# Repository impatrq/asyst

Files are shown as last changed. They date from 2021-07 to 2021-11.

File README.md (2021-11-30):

<!-- PROJECT LOGO -->
<br />
<p align="center">
  <a href="https://github.com/impatrq/asyst">
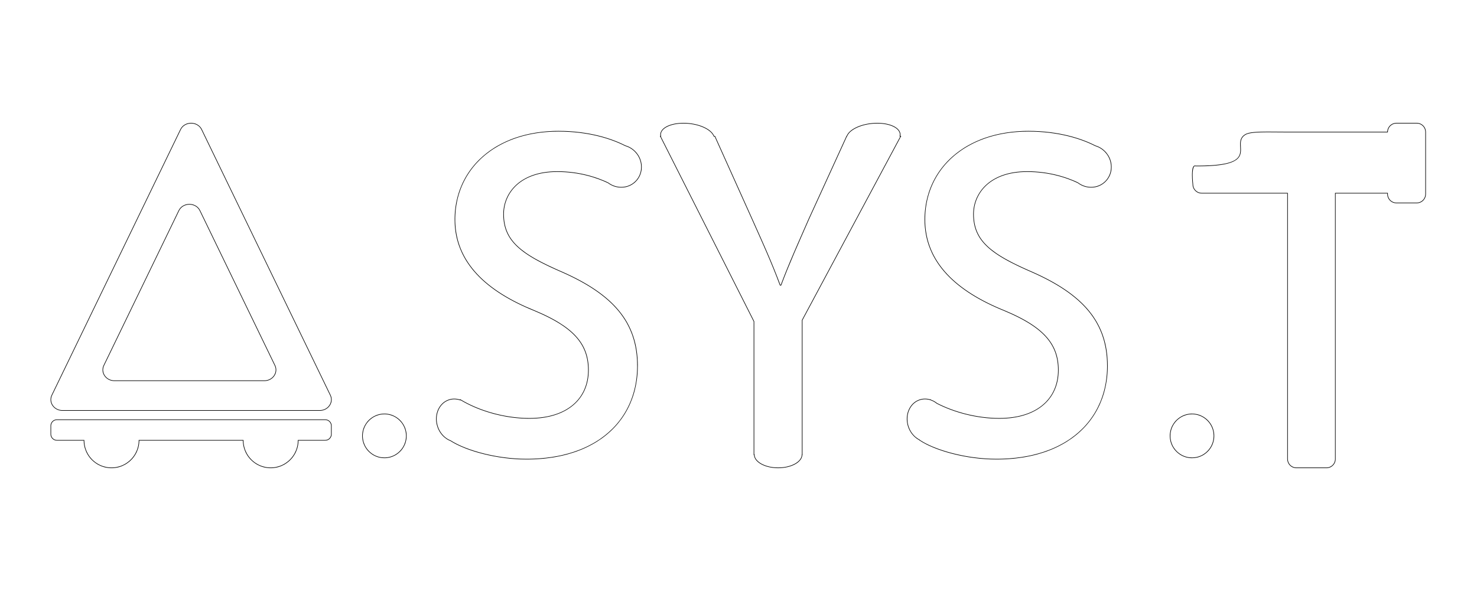
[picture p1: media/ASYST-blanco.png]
    
  </a>

  <h3 align="center">A.SYS.T</h3>
  <h4 align="center">Aeronautical system of tools</h4>

  <p align="center">
    Pedidos inteligentes
    <!-- TABLE OF CONTENTS -->
<details open="open">
  <summary>Contenidos</summary>
  <ol>
    <li>
      <a href="#sobre-el-proyecto">Sobre el Proyecto</a>
    </li>
    <!-- <li>
      <a href="#getting-started">Getting Started</a>
      <ul>
        <li><a href="#prerequisites">Prerequisites</a></li>
        <li><a href="#installation">Installation</a></li>
      </ul>
    </li> -->
    <li><a href="#manual-de-uso">Manual de Uso</a></li>
    <li><a href="#licencia">Licencia</a></li>
    <li><a href="#contacto">Contacto</a></li>
    <!-- <li><a href="#agradecimientos">Agradecimientos</a></li> -->
  </ol>
</details>
<!-- ABOUT THE PROJECT -->

## Sobre el Proyecto

**A.SYS.T (*Aeronautical system of tools*)** es un sistema que facilita el proceso de pedido y entrega de herramientas e insumos en un circuito aeronautico.
**A.SYS.T** ofrece una aplicación con una interfaz amigable en la que los trabajadores ingresarán para hacer los pedidos de herramientas e insumos que necesitarán para efectuar su trabajo, esta app cse comunicará con un servidor que generará un registro digital el cual responderá `¿Quién?, ¿Qué? y ¿Cuándo?` y, a su vez, enviará el pedido para que sea confirmado y posteriormente armado. Una vez listo el pedido un carrito autonomo recibirá el comando para iniciar su viaje y lo transportará hacia el sector de trabajo designado donde los trabajadores podrán retirarlo, usarlo y, posteriormente, devolverlo.

**Benecificios:**
* Al llevar un registro digital de los pedidos se elimina cualquier volumen de papel que se utilizaría para este mismo fin
* Como se puede fitrar el registro ante varios parámetros, se agiliza considerablemente la búsqueda de estos
* Como los pedidos se pueden hacer de forma remota, se reduce el tiempo que lleva realizar el pedido
* Se puede ahorrar el registro de devolución, pues una vez finalizado su uso el carro vuelve y marca como realizada su devolución
* El trabajador hará un menor esfuerzo físico y utilizará menos de su tiempo en el transporte de lo pedido

### Frameworks

* [Django](https://www.djangoproject.com/)
* [Bulma](https://bulma.io/)
* [uPython](https://micropython.org/)

<!-- GETTING STARTED -->
<!-- ## Getting Started

This is an example of how you may give instructions on setting up your project locally.
To get a local copy up and running follow these simple example steps.

### Prerequisites

This is an example of how to list things you need to use the software and how to install them.
* npm
  ```sh
  npm install npm@latest -g
  ```

### Installation

1. Get a free API Key at [https://example.com](https://example.com)
2. Clone the repo
   ```sh
   git clone https://github.com/your_username_/Project-Name.git
   ```
3. Install NPM packages
   ```sh
   npm install
   ```
4. Enter your API in `config.js`
   ```JS
   const API_KEY = 'ENTER YOUR API';
   ``` -->

<!-- USAGE EXAMPLES -->
## Manual de Uso

Manual de uso para el sistema que ofrece A.SYS.T
**[Documentation](https://github.com/impatrq/asyst/tree/master/Manual-de-usuario)**

<!-- LICENSE -->
## Licencia

Distribuido bajo la licencia MIT. Consulte `LICENSE` para obtener más información.

<!-- Distribuido bajo la licencia MIT. Consulte `LICENSE` para obtener más información.

<!-- CONTACTO -->
## Contacto

E-Mail equipo *A.SYS.T* - asyst.official@gmail.com -
Instagram equipo *A.SYS.T* - [a.sys.t](https://www.instagram.com/a.sys.t/)

Link del Proyecto: [github.com/impatrq/ayst](https://github.com/impatrq/asyst)

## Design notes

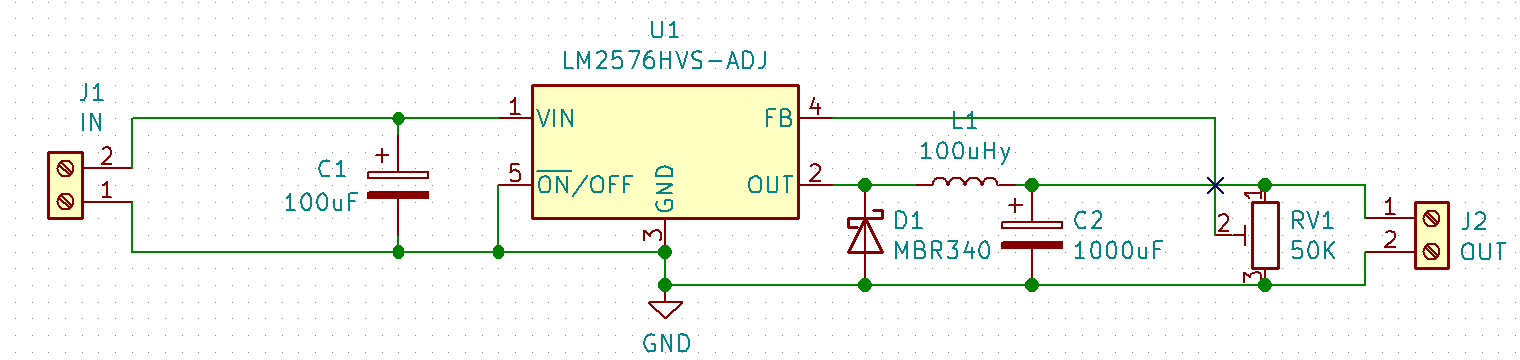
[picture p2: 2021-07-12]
Documentacion/Alimentacion-Digital/Esquemático.png

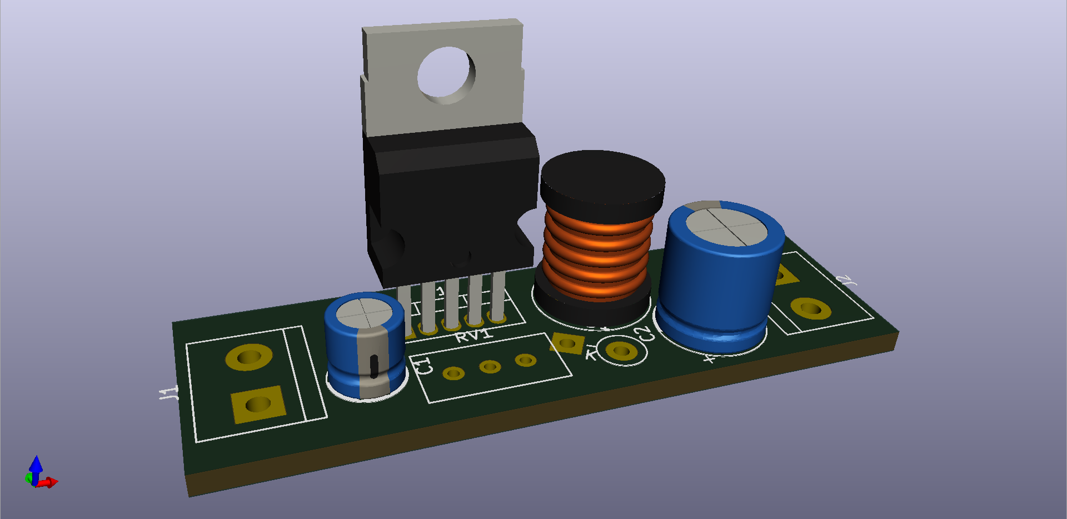
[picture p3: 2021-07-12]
Documentacion/Alimentacion-Digital/circuito 3D.png

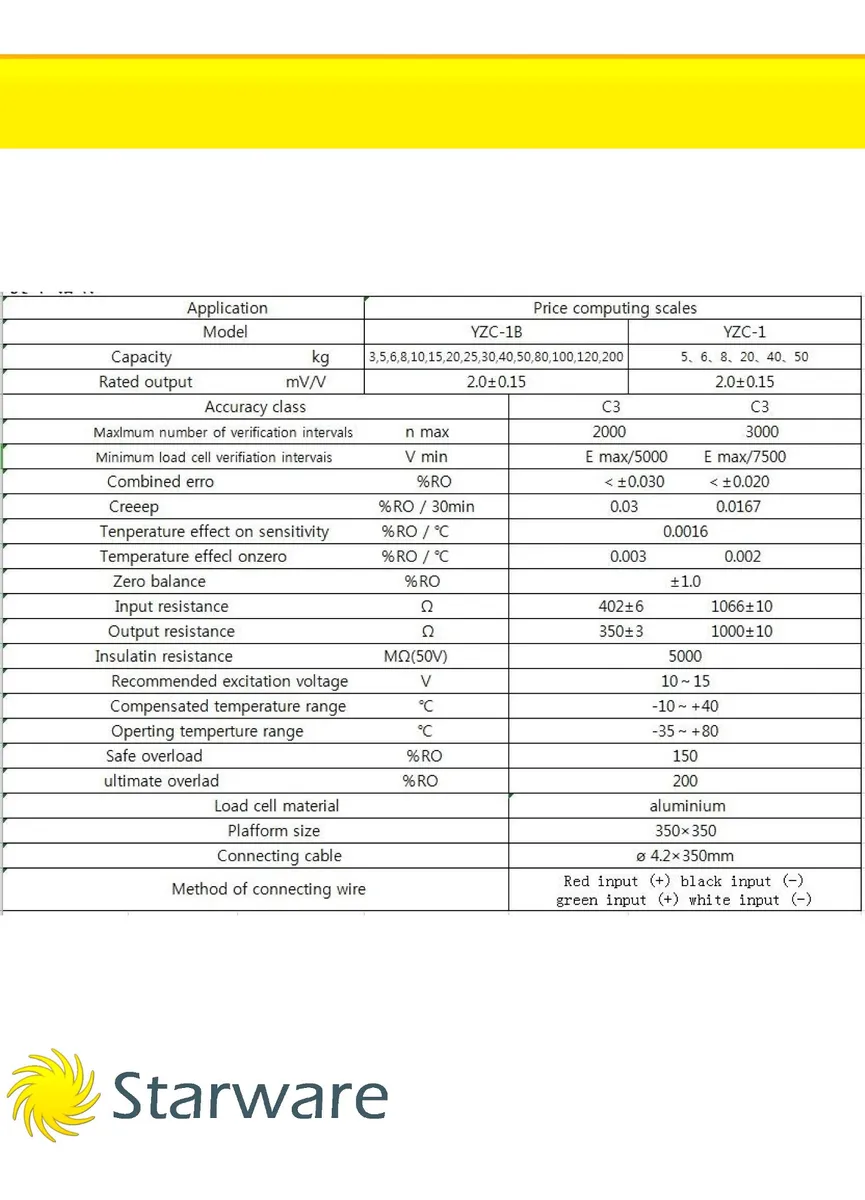
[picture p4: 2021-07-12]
Documentacion/Celda-de-carga/Hoja de datos.png

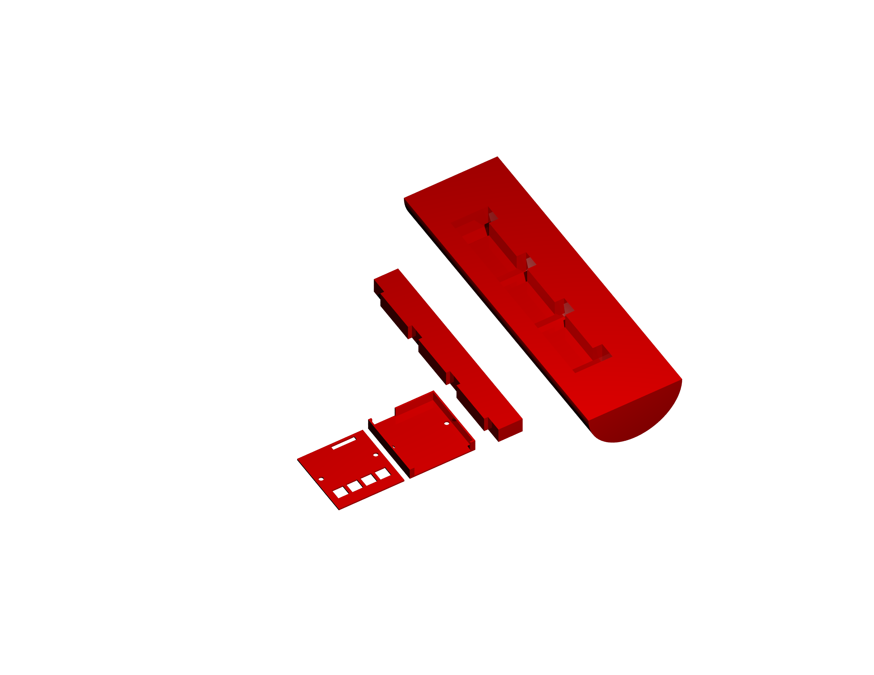
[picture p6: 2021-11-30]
Modelados-3D/soporte-ifr+magnetico/Impresion3D.png

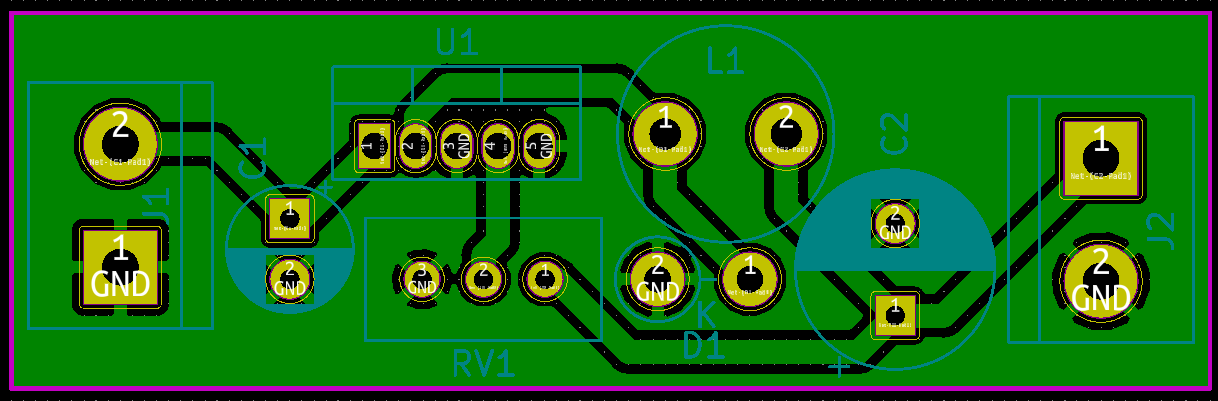
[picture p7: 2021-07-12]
Documentacion/Alimentacion-Digital/PCB.png

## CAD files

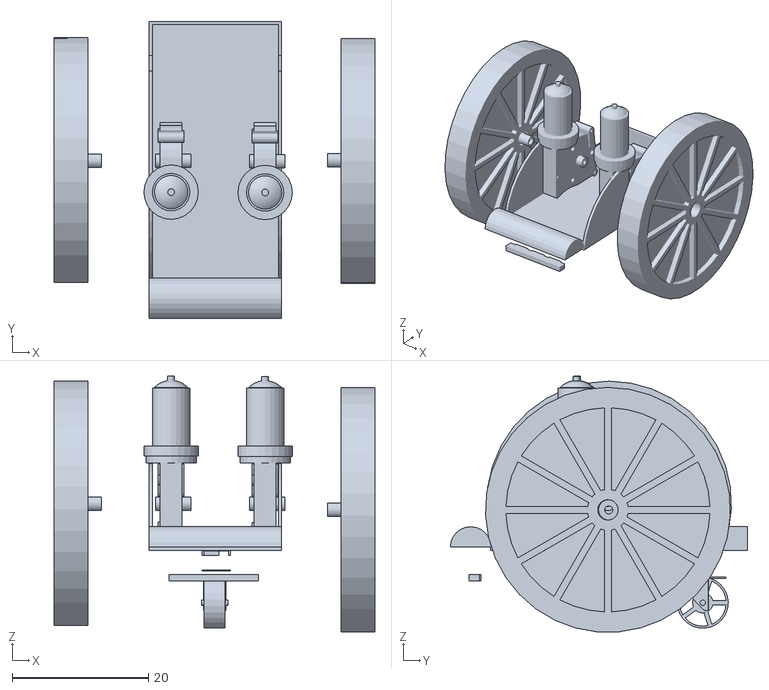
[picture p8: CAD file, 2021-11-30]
Modelados-3D/Carrito-completo/objetos.stl
47.2 x 43.7 x 37.6

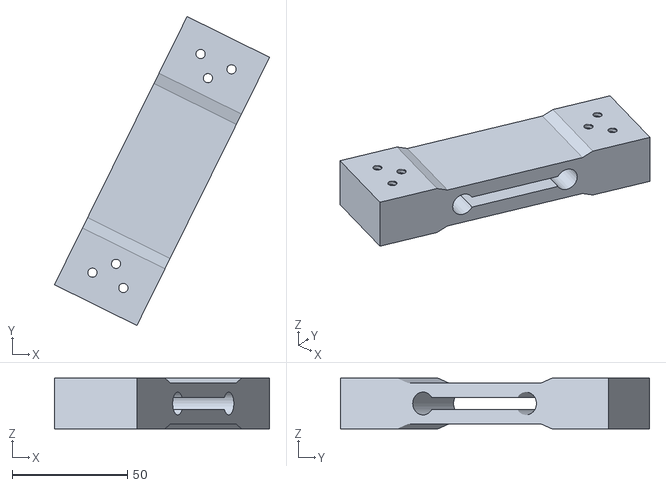
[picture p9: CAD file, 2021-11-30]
Modelados-3D/celda-de-carga/Celda.stl
93.5 x 134.3 x 22.0

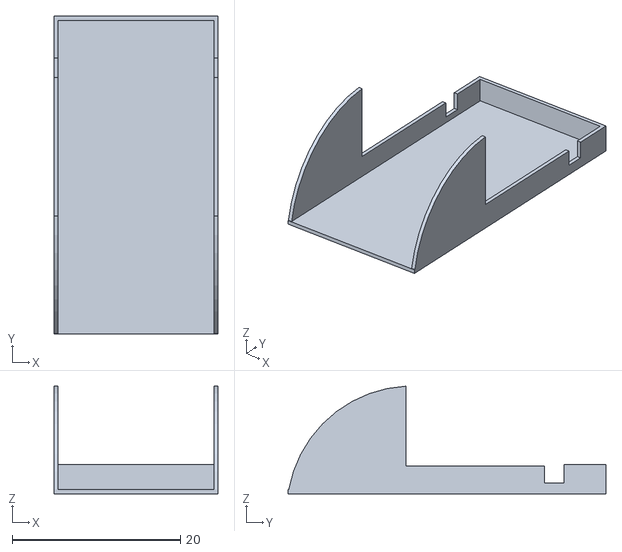
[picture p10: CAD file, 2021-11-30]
Modelados-3D/estructura/estructura3d.stl
19.5 x 37.8 x 12.8

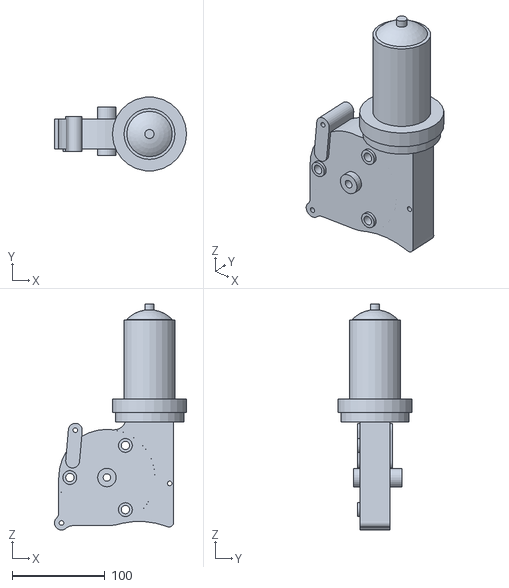
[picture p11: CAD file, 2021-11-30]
Modelados-3D/motor/motor.stl
142.6 x 79.4 x 244.0

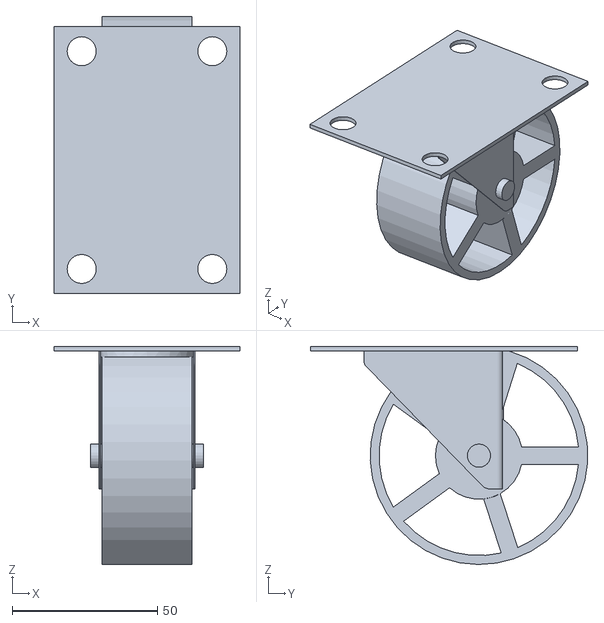
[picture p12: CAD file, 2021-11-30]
Modelados-3D/rueda-giratoria/rueda giratoria3D.stl
64.0 x 95.5 x 75.1

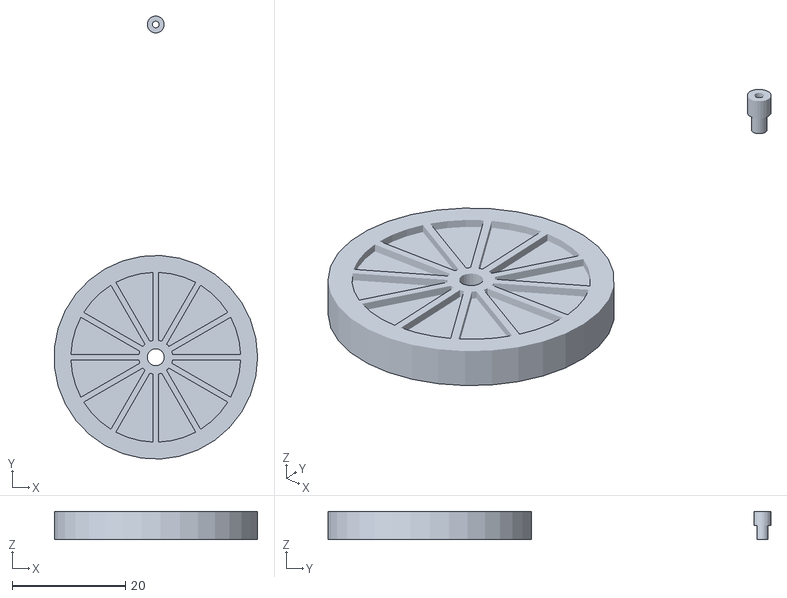
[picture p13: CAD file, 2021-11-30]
Modelados-3D/rueda/rueda+adaptador eje motor3d.stl
35.9 x 78.3 x 5.00

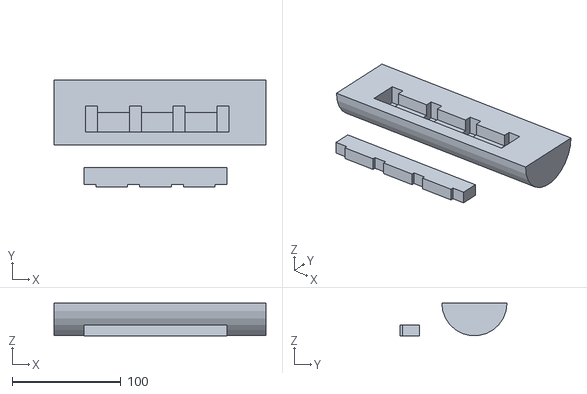
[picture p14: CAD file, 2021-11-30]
Modelados-3D/soporte-ifr+magnetico/soporte sensores.stl
195.0 x 98.4 x 30.0

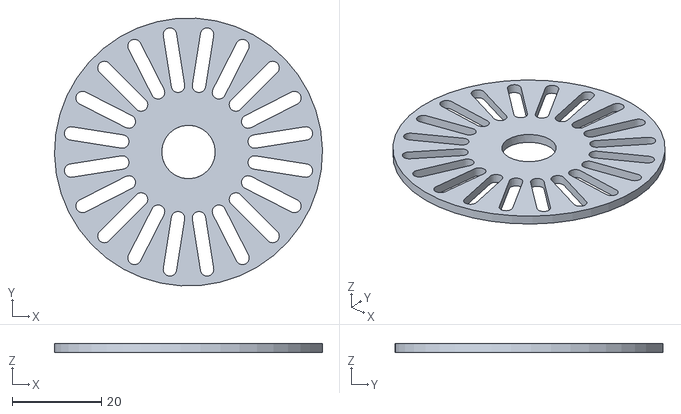
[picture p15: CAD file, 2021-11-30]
Modelados-3D/rueda-optica-rpm/encoder opt.stl
60.0 x 59.9 x 2.00

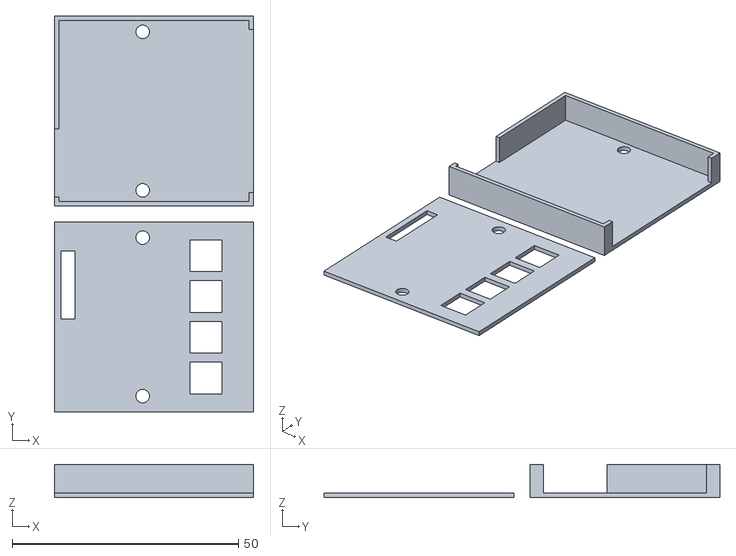
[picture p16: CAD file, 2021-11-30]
Modelados-3D/soporte-ifr+magnetico/calibrador.stl
44.0 x 87.4 x 7.37

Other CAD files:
Documentacion/Celda-de-carga/Celda.dwg
Modelados-3D/rueda-optica-rpm/rueda optica rpm.dwg
Modelados-3D/estructura/estructura.dwg
Modelados-3D/rueda-giratoria/rueda giratoria.dwg
Modelados-3D/rueda/ruedaa+daptador eje motor.dwg
Modelados-3D/soporte-ifr+magnetico/Dibujo1.dwg
Modelados-3D/Carrito-completo/objetos.dwg
Modelados-3D/celda-de-carga/Celda.dwg
Modelados-3D/estructura/estructura3d.dwg
Modelados-3D/motor/motor.dwg
Modelados-3D/rueda-giratoria/rueda giratoria3D.dwg
Modelados-3D/rueda/rueda+adaptador eje motor3d.dwg

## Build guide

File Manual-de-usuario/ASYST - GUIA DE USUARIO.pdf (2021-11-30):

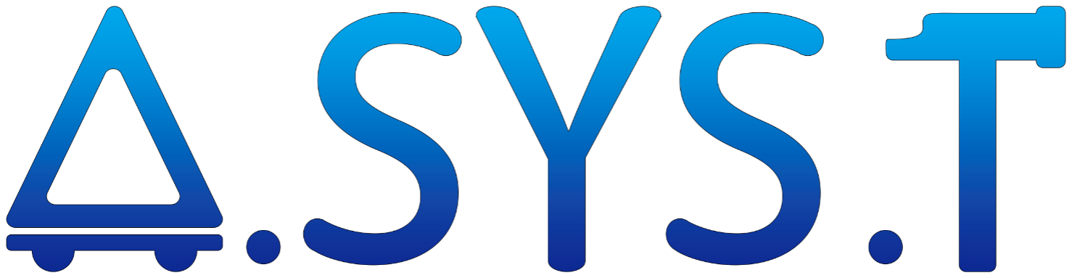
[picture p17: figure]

E.E.S.T. N°7 “T.R.Q.”
Juan B. Justo 79, Quilmes
asyst.official@gmail.com
Proyecto A.SYS.T; 2021

# “AERONAUTIC SYSTEM OF TOOLS”

# MANUAL DE USUARIO

INTRODUCCIÓN | 2
Por qué elegir A.SYS.T: | 2
A. APLICACIÓN | 3
1.0. Identifíquese: | 3
2.0. Interfaz de usuario: | 4
2.1. Interfaz de Trabajador: | 5
2.2. Interfaz de Staff: | 6
B. VEHÍCULOS | 9
2.0. Recorrido por el vehículo: | 10
2.1. Envío del vehículo: | 10
2.2. Viaje | 11
2.3. Destino: | 11
2.4. Regreso: | 11
2.5 Devolución: | 11
C. INSTALACIÓN | 12

## INTRODUCCIÓN

## Por qué elegir A.SYS.T:

Comparativamente entre lo que nuestro sistema digital de registro de pedidos plantea y lo que el anticuado sistema ofrece vemos mejoras en:

✔Considerable reducción del espacio físico ocupado por los archivos en papel.
✔Gran agilización a la hora de la búsqueda entre los registros. ✔Reducción del tiempo necesario para hacer los pedidos.
✔Reducción de riesgos de daño o extravío de la documentación.

Por otra parte, cuando comparamos nuestra alternativa del transporte de los carros de herramientas con el viaje manual observamos las siguientes mejoras:

✔Se puede ahorrar el registro de devolución, pues una vez finalizado su uso el carro vuelve y marca como realizada la devolución.
✔El trabajador hará un menor esfuerzo físico e invertirá menos tiempo en el transporte de herramientas.

Teniendo en cuenta el análisis de costo/beneficio, podemos concluir que:

✔Este producto ofrece una mejora a un sistema que ya existe, volviéndolo más ágil y seguro, dos factores que en un taller aeronáutico consideramos esenciales.
✔Ofrece mucha mayor seguridad en el archivado, ya que no depende de documentos físicos que puedan dañarse o perderse.
✔Se reduce la cantidad de esfuerzo físico realizado por los trabajadores, mientras que se asegura la fluidez y comodidad de la rutina laboral, resultando en horas de trabajo más productivas y menos interrumpidas.
✔El uso de su interfaz no requiere más que una computadora o un teléfono móvil, volviéndo accesible en prácticamente cualquier taller, ya que no se necesitará realizar compras adicionales.

## A. APLICACIÓN

## 1.0. Identifíquese:

Cada trabajador puede y deberá crear un perfil mediante el cual puede utilizar todas las funciones de nuestro sistema. Dependiendo de la clase de usuario tendrá acceso a un panel u otro.

- El primer tipo de usuario que abarca el sistema es el “Trabajador”. Este usuario es el que tiene el rol en el taller de pedir y utilizar las herramientas.
- El segundo tipo de usuario es el “Staff”. Este usuario corresponde a los encargados de la oficina técnica y el pañol. Sus
funciones son las de gestionar los pedidos
realizados por los “Trabajadores”, y

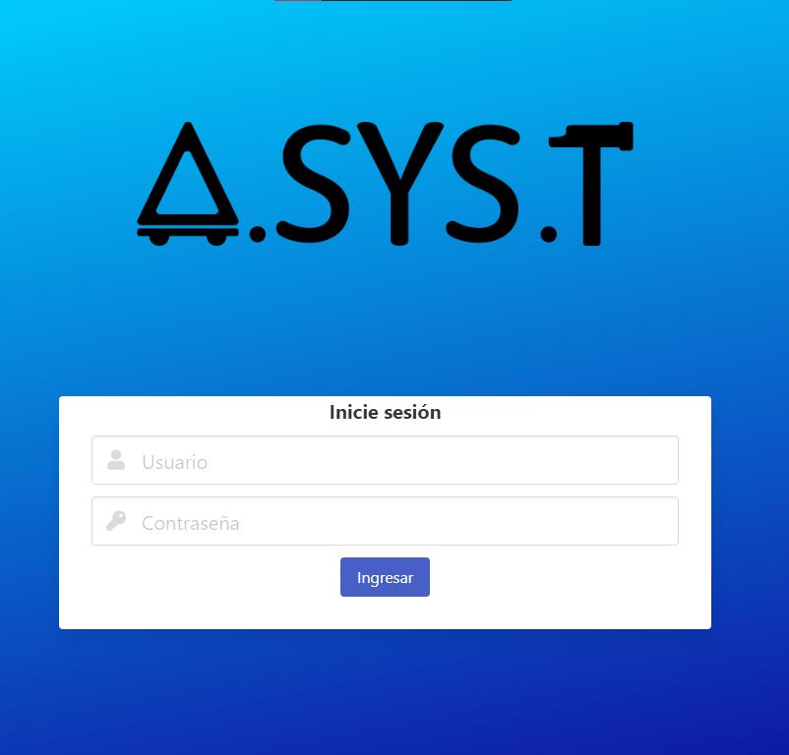
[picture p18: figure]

cargar los vehículos con las herramientas e insumos que el primero solicita; también debe gestionar el Stock del taller, tener acceso a los registros de pedidos previos y gestionar la flota de vehículos autónomos.

Cuando ingrese por primera vez al sistema, verá una pantalla rotulada “inicie sesión”. Si tiene ya tiene una cuenta puede ingresar y seguir la guía en la página 4.
Si no posee una cuenta deberá dirigirse a la pantalla de registro, donde se le pedirá que ingrese 5 datos, los cuales son:
- Su nombre de usuario con el cual se
identificará en el sistema.
- Su nombre completo, para que sus superiores puedan identificarlo en el sistema.
- Su correo electrónico laboral, al cual le llegará un correo en caso de que solicite restablecer su cuenta.
- Su contraseña, será pedida dos veces para corroborar que la ha escrito correctamente.
- El rol que posee en la empresa, marque la opción “Es staff” en caso de que sea un trabajador del pañol o la oficina técnica. Caso contrario no
debería seleccionar esta opción ya
que no le servirá para el trabajo.

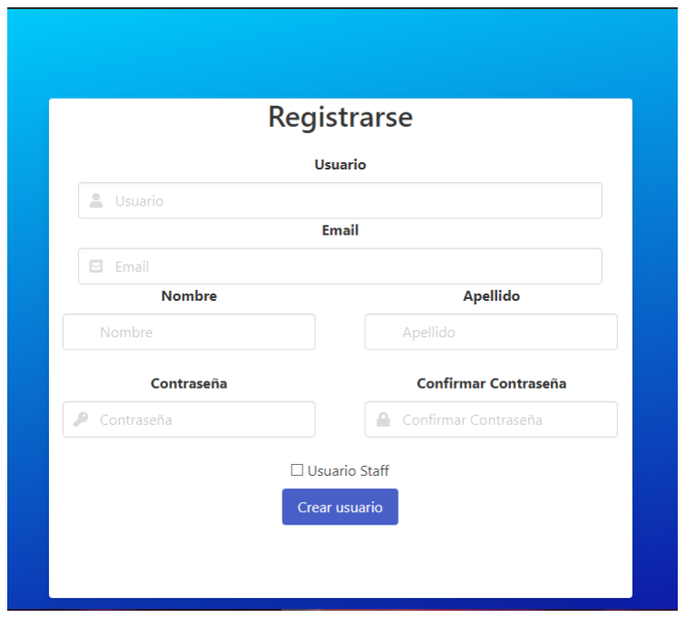
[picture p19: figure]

Con estos datos podrá crear su cuenta y comenzar a utilizarla. En caso de que tenga algún dato faltante o erróneo (véase un nombre de usuario ya existente o la contraseña mal confirmada), el proceso será interrumpido y se le informará para que reintente la creación de su cuenta.

## 2.0. Interfaz de usuario:

La interfaz es bastante intuitiva de por sí, ya que pensamos en la experiencia de usuario como principal factor, sin embargo no está de más tener un par de consideraciones en cuenta.

En todas las interfaces (excepto la de iniciar sesión y registrarse), tendrá una barra superior por la que podrá navegar entre las distintas funciones que el sistema tiene para ofrecer, esta se encuentra en la esquina superior derecha de la pantalla, y se divide en dos grupos.

1) El primer grupo se trata de las funciones del sistema, probablemente las opciones que tenga disponibles no sean las mismas que se ilustran, pero la función es la misma: alternar entre las funciones del sistema con un click.
2) El segundo apartado es ese icono que se ve a la derecha, si posa el mouse sobre este icono podrá ver la inscripción “logout”. Es decir que con este botón cerrará la sesión y volverá a la pantalla de Inicio de Sesión.
Una vez con eso aclarado podemos continuar con la interfaz específica de cada tipo de usuario.

### 2.1. Interfaz de Trabajador:

Lo primero que se encuentra un usuario de este estilo al ingresar es una pantalla donde puede ver el Stock del taller y seleccionar las cosas que requiere y en que cantidad lo requiere. Nótese que realmente la lista es bastante larga. Se puede observar que en el encabezado de la lista de búsqueda hay tanto un filtro de escritura (barra superior) como también hay un filtro de opciones múltiples: “Todos/Herramientas/Insumos”.

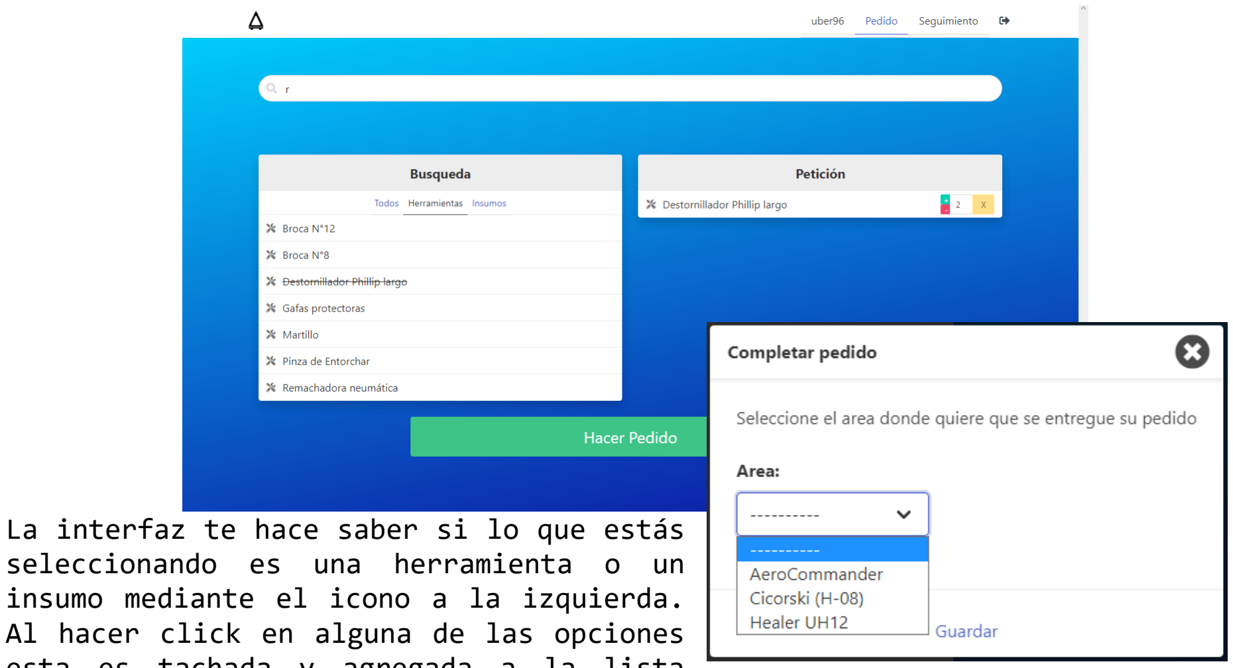
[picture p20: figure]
seleccionando es una herramienta o un

La interfaz te hace saber si lo que estás

insumo mediante el icono a la izquierda.
Al hacer click en alguna de las opciones
esta es tachada y agregada a la lista
derecha. Se puede ver que a la izquierda de cada elemento de la lista de seleccionados hay un número y tres botones. El numero es la cantidad de ese insumo que se solicita, el cual se modifica mediante los botones “+/-”, si se equivocó o cambió de parecer el boton amarillo “X” revierte la selección y lo destacha de la lista izquierda.

Cuando se terminó de pedir lo que requiere, se clickea el botón verde “hacer pedido”, momento en el cual se despliega una ventana emergente, la cual le permite seleccionar el área al que debería llegar el pedido.

Una vez completado el pedido se envía a la oficina técnica o en su defecto al pañol. El trabajador se redirecciona a la segunda pantalla, denominada “Seguimiento”. Desde esta zona de la interfaz puede seguir su orden en tiempo real, teniendo información de si fué aprobado o no su pedido y donde se encuentra este.

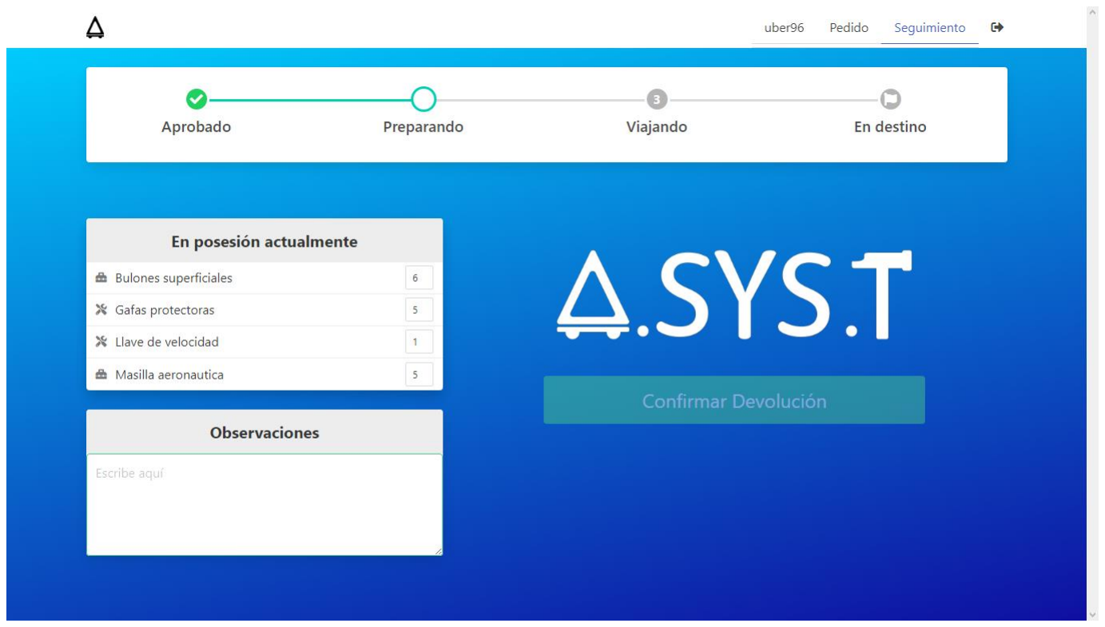
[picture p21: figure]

Como se ve en la imagen adjunta, el botón de la devolución está deshabilitado. Esto es porque no se puede hacer una devolución mientras no se tengan en posesión las herramientas. A la derecha hay dos cuadros, uno es donde se hace una observación al momento de devolver las herramientas, de forma tal que quede registrado si por ejemplo se dañó una herramienta o se devuelven insumos que se habían solicitado de más, el otro es un recordatorio de las herramientas que se tienen a cargo.

Este es el abanico de opciones y funcionalidades que tienen los Trabajadores.

### 2.2. Interfaz de Staff:

La interfaz de los usuarios de clase “Staff” es bastante más extensa, ya que son los que mantienen y le dan vida al sistema, además de ser el nexo entre la flota de vehículos autónomos y los trabajadores.

Al iniciar sesión en una cuenta “Staff” lo primero que vemos es la pantalla a la que denominamos “pedidos”. Esta pantalla es bastante intuitiva, se ven múltiples tarjetas, cada una con
fecha, nombre y la lista de herramientas
que fué solicitada.

Las tarjetas tienen algunas herramientas que se muestran, pero si la lista es lo suficientemente larga se ve un “ver mas” el cual despliega una ventana emergente al ser clickeada, en la cual se detallan
todos | los | insumos | que | solicitó | el
usuario.

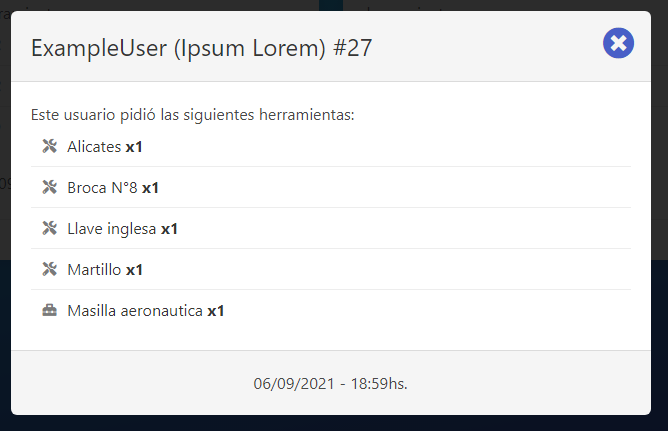
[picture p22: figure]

En el pie de cada tarjeta se ven dos botones, se entiende que uno es para aprobar y otro es para rechazar el pedido en cuestión. Al ser seleccionada la opción de aprobación el sistema leerá los vehículos disponibles y asignará uno si está disponible, diciéndole a usted en qué vehículo deberá cargar las herramientas. De otra manera no aceptará el pedido y le informará a usted que la flota está en uso para que reintente más adelante. Caso contrario se despliega una ventana diferente, en el cual se deberá escribir el motivo del rechazo. Este mensaje será visto por el Trabajador y quedará grabado en los registros.

Otra función que tiene su perfil Staff es el del Stock. El funcionamiento de esta es bastante similar a su contraparte del lado “trabajador”, ya que
posee | dos | filtros: | uno | por | nombre | y | otro | por | opción | múltiple
“Todos/Herramientas/Insumos”, la lista se encuentra ordenada de forma alfabética, y tiene dos botones en cada elemento de la lista que son “editar y eliminar”. Al presionar eliminar se remueve de la base de datos esta herramienta, como indica su nombre.

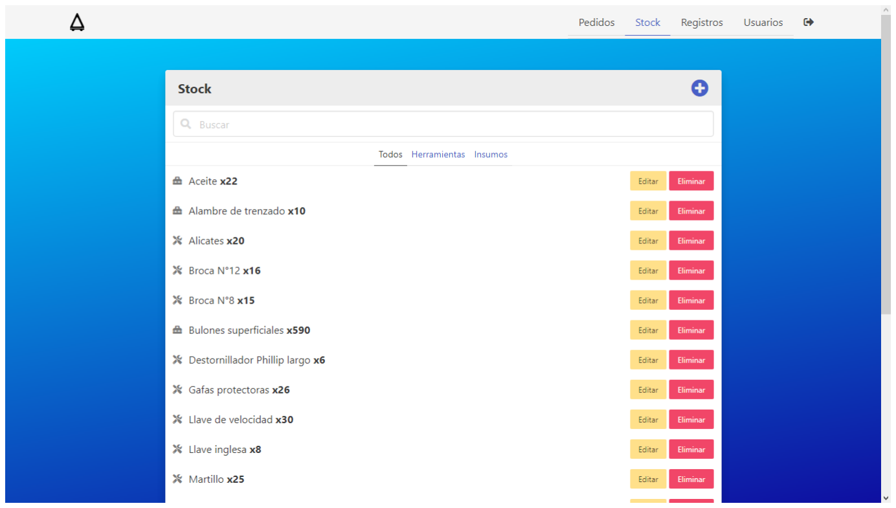
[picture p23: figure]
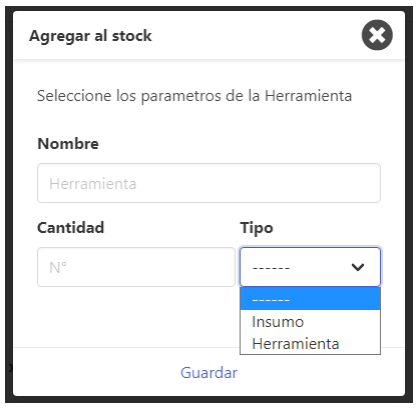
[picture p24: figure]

Las opciones editar y añadir (el “+” de la esquina superior derecha) son bastante similares, ya que ambos despliegan una ventana casi idéntica, con la diferencia que en uno se verán los datos actuales del elemento a editar y en el otro se ven todos los campos vacíos. A continuación se muestra la ventana antes detallada, al hacer click en guardar se actualiza la
información, | agregando/modificando | la
herramienta o insumo.

En caso de que el tipo no sea válido se desplegará una advertencia en rojo y no se hará cambio hasta que sea corregido. la X de la esquina superior esconde la ventana, cancelando la operación.

Finalizando con la interfaz del “Staff” se observa la pantalla “Registros”.

Esta pantalla le permite leer los pedidos aprobados y rechazados, mostrándolos de una forma cómoda. Además, brinda una serie de 4 etapas de filtrado de la información, de modo que se pueda buscar de manera eficiente lo que se requiere.

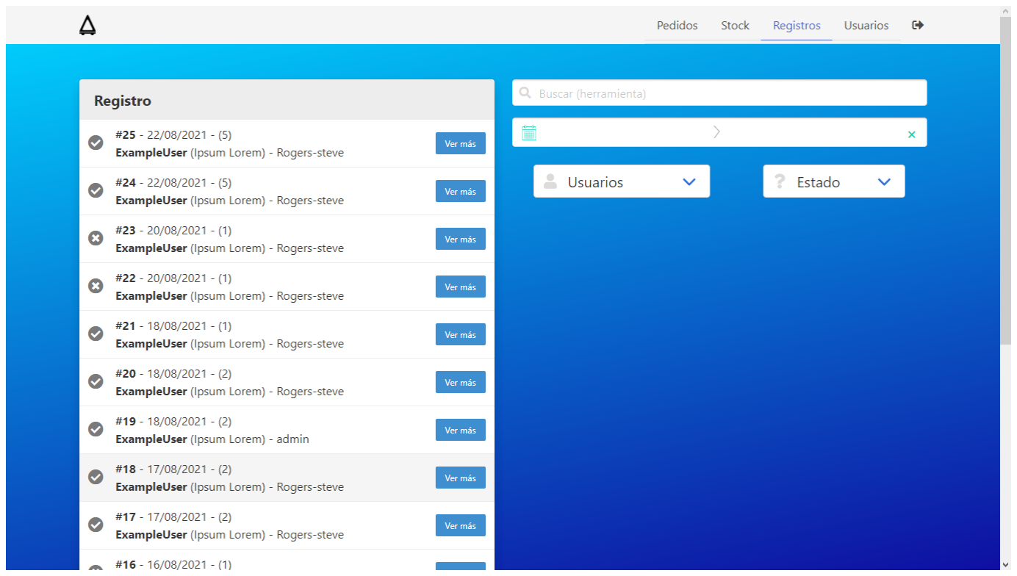
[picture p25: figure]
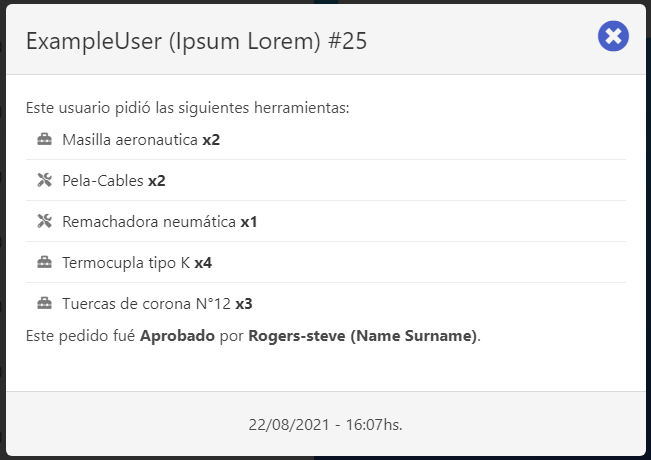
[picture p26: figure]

A la derecha se pueden ver los pedidos, con su estado (icono), id, fecha, herramientas que se pidieron y Staff a cargo de su aprobación. Se ve un botón de “ver más”, que desplegará una ventana emergente donde se podrá ver
específicamente | qué | insumos | se
pidieron, en qué cantidad y la hora del pedido.

La parte más interesante para detallar es la de los filtros:

- Filtro de Usuarios: Es bastante intuitivo, al hacer click en él se despliega una lista de opciones con todos los usuarios, ya sean Trabajadores o Staff (Rotulados con una “S”). Al tener uno seleccionado se activa el filtro, reduciendo de las opciones totales a los que cumplen la condición de tener al seleccionado como autor (o en caso de seleccionar un Staff que haya sido el moderador de ese pedido).

- Filtro de Estado: Este filtro es en funcionamiento idéntico al anterior, solo que en este caso las opciones disponibles son “aprobado/rechazado”.
- Filtro por Herramienta: En este caso se trata de una entrada de texto, la finalidad de este filtro es que por ejemplo si se descubre que falta un martillo se escribe “martillo” en la barra de búsqueda, y la pagina reduce la lista del registro a los registros que contengan martillos como uno de los elementos solicitados.
- Filtro por Intervalo Temporal: Este
es algo más complejo, ya que al hacer click en él se despliega un calendario con la fecha actual indicada. Se puede retroceder los meses o años que haga falta, y se seleccionan dos fechas. La más antigua será la fecha de inicio y la más actual será el punto de cierre. Con el rango de tiempo activo el registro solo mostrará en pantalla los registros correspondientes a ese intervalo de tiempo. Por ejemplo si seleccionara el 1/8 y el 31/8 le
serían | mostrado | solo | los | pedidos
realizados el mes de Agosto.

Cabe aclarar que los filtros se aplican de

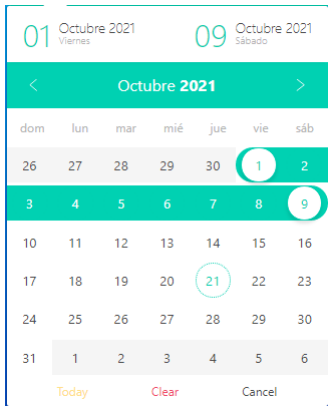
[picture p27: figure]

forma conjunta, de modo que se podrían ver “los martillos pedidos en agosto” o “Los pedidos rechazados de Juan Martín”

## B. VEHÍCULOS

En este apartado del manual veremos cómo utilizar la flota correctamente, incluyendo tanto la experiencia de usuario “Trabajador” como la del “Staff”. Le sugerimos que haya leído la interfaz de usuario con anterioridad.

## 2.0. Recorrido por el vehículo:

El vehículo posee un abanico de artefactos que es útil identificar para saber qué ocurre con este o los cómos y porqués de su actuar.

- Sensor ultrasónico: este sensor es utilizado para detectar cercanía con obstáculos, si un obstáculo físico se encuentra peligrosamente cerca del vehículo en movimiento, este lo detectará y frenará para evitar la colisión con el personal u objetos
- Balanza: Mediante el cual el vehículo puede saber cuanto es la carga de peso actual. La función que esta tiene a fines prácticos es la de evitar que el vehículo arranque con sobrepeso, garantizando un correcto funcionamiento.
- Display LCD: este display se utiliza para mostrar en pantalla cuanto peso hay actualmente sobre la celda de carga, esto es para que el usuario pueda ver cuanto peso está cargando y que tanto se acerca o pasa del peso máximo que tiene el vehículo.
- Buzzer: este elemento emite sonido siempre que las condiciones de arranque no sean indicadas, siendo ellas un exceso en el peso máximo, forzar envío de materiales sin pedido asignado en el servidor o forzar devolución sin confirmar con el servidor que se devuelven las cosas.
- Botón de confirmación física: Este botón está situado en la parte superior del vehículo y su función es hacer que arranque cuando es pulsado. Al cargar o descargar las herramientas, este debe
ser | pulsado.

### 2.1. Envío del vehículo:

Una vez el Staff aprueba un pedido y este tiene un vehículo disponible, la interfaz indica en qué unidad cargar las herramientas. Entonces el “Staff” se dirige hacia este vehículo, carga las herramientas y presiona el botón de confirmación física. Al presionarlo el carrito debería de iniciar el viaje si las condiciones son correctas (que el peso esté entre los límites, que el carrito tenga una dirección asignada y que esté sobre la línea). Si alguno de estos factores no es correcto sonará el Buzzer o alarma y el display LCD mostrará el problema (abortando el viaje hasta la nueva pulsación).

### 2.2. Viaje

El carrito sale hacia el destino marcado en la petición luego de salir. El vehículo puede iniciar en el pañol o en el destino, en este último caso la unidad volverá sobre sus pasos hacia el pañol. Durante este periodo no hay casi interacción con el usuario. Lo que se puede destacar es que en el apartado “seguimiento” de la interfaz informa su estado. El vehículo posee como medida de seguridad el sensor ultrasónico, que impide que se choque, frenando al encontrar un obstáculo en su camino, hasta que este se despeje. En caso de que por algún motivo su viaje falle, automáticamente inicia una secuencia para reanudarlo. Si esta no surge ningún efecto, informa al personal que se encuentra “perdido”. En condiciones normales esto último no ocurre, si no que llega a su destino y termina allí su primer viaje.

### 2.3. Destino:

Cuando la unidad llega al área de trabajo, el personal que la solicita debe descargar las herramientas, posterior a eso presiona el botón de confirmación física. En este instante el vehículo hace un giro de 180° en su lugar y comienza un regreso sobre sus pasos, para llegar al pañol.

### 2.4. Regreso:

Durante este segundo tramo de viaje la unidad se comporta igual que en el primero. La diferencia es que cuando llega al pañol este irá a su estación de carga, donde quedará en reposo cargando su batería. Esto continuará hasta que vuelva a ser solicitado.

### 2.5 Devolución:

Finalizado el trabajo de los técnicos estos devolverán sus herramientas usando la flota, para esto presionan el apartado de la interfaz y se le informa al Staff. El personal del pañol debe en este momento presionar la confirmación física del vehículo y este se dirigirá como lo hizo anteriormente, con la diferencia de que viaja vacío y vuelve cargado con las herramientas que se solicitaron.

# C. INSTALACIÓN

El Taller no debe preocuparse por instalar el sistema y la infraestructura que este requiere, ya que este servicio corre por cuenta del equipo de A.SYS.T. La instalación consiste en:

- La puesta a punto de la flota.
- La instalación del sistema en un servidor o computadora centralizada.
- La configuración de la flota al servidor (como la red WiFi, la matrícula, etc).
- La instalación de los caminos (líneas).
- Las bifurcaciones magnéticas (y los fines de zona).
- el registro de las zonas en el servidor.
- La instalación de las estaciones de carga autónoma.

En caso de que se quiera añadir otra unidad a la flota basta con adquirir
otra | estación | de | carga | y | configurar | esta | nueva | unidad.

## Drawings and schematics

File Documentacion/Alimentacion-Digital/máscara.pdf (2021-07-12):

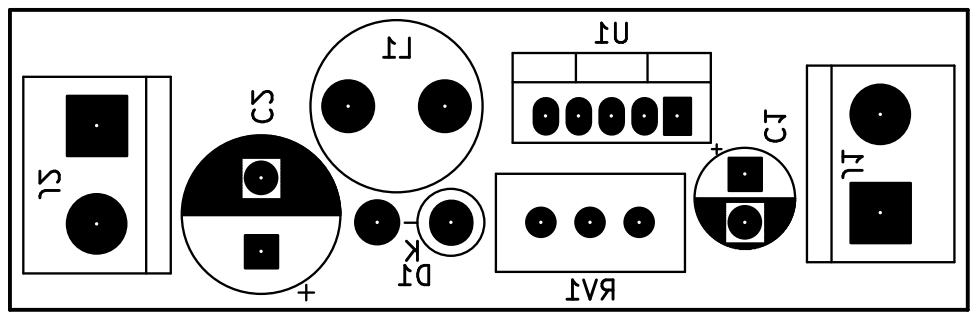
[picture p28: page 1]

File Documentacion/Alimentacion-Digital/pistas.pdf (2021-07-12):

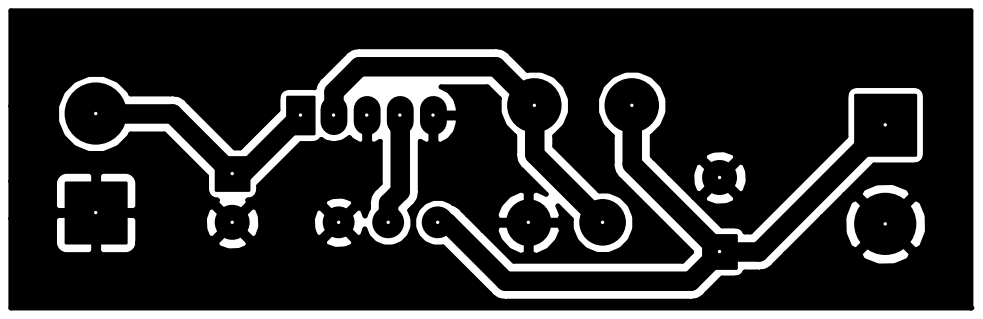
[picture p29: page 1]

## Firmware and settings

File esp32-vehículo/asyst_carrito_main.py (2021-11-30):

#----------------------Librerías a utilizar-----------------------
from machine import Pin, PWM
import time
import ujson 
import urequests
import time
import lib_asyst as lib

sta_if = network.WLAN(network.STA_IF);    # instancia el objeto -sta_if- para controlar la interfaz STA
sta_if.active(True)                       # activa la interfaz STA del ESP32
sta_if.disconnect()
if sta_if.isconnected(): sta_if.disconnect()
#print(sta_if.scan())
sta_if.connect("Avionica 2B","Atlantida2020")    # inicia la conexión con el AP
while not sta_if.isconnected():
    time.sleep(0.5)
#print("conectado:", sta_if.isconnected())

#-----------------------Pines a utilizar---------------------------
#No se pueden usar: 6 al 11, 20, 23, 24, 28 a 31, 37, 38 

pin_sensor_IFR    = [0,0,0] #4,5,12,13,14
pin_sensor_IFR[0] = Pin(34, Pin.IN)
pin_sensor_IFR[1] = Pin(35, Pin.IN)
pin_sensor_IFR[2] = Pin(32, Pin.IN)
#pin_sensor_IFR[3] = Pin(33, Pin.IN)

freq_pwm = 300
pin_M_L_forw      = Pin(27, Pin.OUT)
pin_M_L_back      = Pin(14, Pin.OUT)
pin_M_R_forw      = Pin(12, Pin.OUT)
pin_M_R_back      = Pin(13, Pin.OUT)
pin_M_L_pwm       = PWM(Pin(26),freq_pwm)
pin_M_R_pwm       = PWM(Pin(25),freq_pwm)
pin_confirmacion  = Pin(18, Pin.IN, Pin.PULL_DOWN)

pin_sensor_MG     = Pin(21, Pin.IN)
pin_sensor_MG_2   = Pin(4, Pin.IN)

#US_trigger_pin    = 0
#US_echo_pin       = 15
#sensor_US = lib.HCSR04 (US_trigger_pin, US_echo_pin)


#----------------Variables y objetos a utilizar---------------------

URL = lib.URLs('http://192.168.0.4:8000/carrito/?matricula=420','http://192.168.0.4:8000/carrito/?matricula=420',420)#ipGet, ipPost, matricula
direccion = 0
destino = []   #Próximamente se le preguntará al servidor el destino
countIman = 0
delay = 0
M_L_forw=0
M_L_back=0
M_L_pwm=0
M_R_forw=0
M_R_back=0
M_R_pwm=0
#confirmacion = 0
start = 0
sensor_IFR=[0,0,0]
interrupcion = 0
delay = False
esperandoMG2 = False


#pines = [boton_frenado,sensor_IFR, alarma_balanza, sensor_MG]
#--------------------------------------------------------------

while 1:
    #print("final de recorrido")#!-----------------
    #print(pin_confirmacion.value())
    time.sleep(0.1)
    #lib.regular_velocidad_motores(pin_M_L_pwm,pin_M_R_pwm,1,M_L_pwm,M_R_pwm)#*para asegurarnos que empiece frenado
    while pin_confirmacion.value()==0 and start==0:
        #print("valor:",pin_confirmacion.value())#!---------------------------
        time.sleep(0.1)
        if pin_confirmacion.value()==1:#todo: añadir Try para ver si recibe algo
            posicion_actual = []
            destinoPanol    = []#La cantidad de ceros depende del circuito
            destino = URL.get_from_server()
            for i in destino:
                posicion_actual.append(0)
                destinoPanol.append(0)
            #print(destino)#!------------------------------------------
            start = 1
            #print("EMPEZAMOS UN RECORRIDO")#!-------------------------------------------
            break
    
    while start:
        sensor_IFR, sensor_MG, sensor_MG_2 = lib.actualizar_valores(pin_sensor_IFR, pin_sensor_MG, pin_sensor_MG_2)
        
        direccion = lib.corregir_rumbo(sensor_IFR)
        
        if sensor_MG: 
            #esperandoMG2=True
        #if esperandoMG2: direccion = 3
        #if sensor_MG_2 and esperandoMG2:
            #esperandoMG2 = False
            destino, direccion, countIman, posicion_actual, delay,start= lib.reconocimiento_sector(destino,countIman,destinoPanol,posicion_actual,URL)
            #print(destino, posicion_actual)
            time.sleep(1)#borrar cuando esten ambos sensores
        #interrupcion = lib.frenado(sensor_US)
        M_L_forw,M_L_back, M_L_pwm,M_R_forw,M_R_back, M_R_pwm = lib.regular_direccion(direccion)
        lib.regular_sentido_motores(pin_M_L_forw,pin_M_L_back,M_L_forw,M_L_back,  pin_M_R_forw,pin_M_L_back,M_R_forw,M_R_back)

        if direccion==6:#* SE MANTIENE FRENADO HASTA QUE SE PULSA EL BOTÓN DE CONFIRMACIÓN FÍSICA
            lib.regular_velocidad_motores(pin_M_L_pwm,pin_M_R_pwm,1,M_L_pwm,M_R_pwm)
            #print("esperando botón de confirmación")#!---------------------------
            while not pin_confirmacion.value():pass
            #print("REGRESANDO...")#!----------------
            time.sleep(3) #tiempo de espera para no atropellar a nadie

        lib.regular_velocidad_motores(pin_M_L_pwm,pin_M_R_pwm,interrupcion,M_L_pwm,M_R_pwm)

        if not interrupcion:#* EL PROGRAMA SE PAUSA HASTA TERMINAR DE COMPLETAR LOS GIROS A 90° O 180°
            if delay and direccion==6:
                time.sleep(2) #cambiar por el tiempo que corresponde
                delay = False
            elif delay: 
                time.sleep(1)#cambiar por el tiempo que corresponde
                delay = False      
        #terminar de hacer xd
        #if direccion==8:    

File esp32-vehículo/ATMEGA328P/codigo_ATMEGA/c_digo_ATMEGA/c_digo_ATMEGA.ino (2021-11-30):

#include "HX711.h"
#define DEBUG_HX711
//------------------
#include  <Wire.h>
#include  <LiquidCrystal_I2C.h>
//LiquidCrystal_I2C lcd(0x27, 2, 1, 0, 4, 5, 6, 7, 3, POSITIVE);
LiquidCrystal_I2C lcd(0x27, 16, 2);

// Parámetro para calibrar el peso y el sensor
#define CALIBRACION1 20780.0           //MODIFICAR ESTE VALOR DEPENDIENDO EL VALOR OBTENIDO EN LA ETAPA DE CALIBRACIÓN
#define CALIBRACION2 20780.0
// Pin de datos y de reloj
byte pinData = 3;
byte pinClk = 2;
byte pinData2 = 4;
byte pinClk2= 5;
// Objeto HX711
HX711 Bascula;
HX711 Bascula2;
//pines y variables de Buzzer
unsigned int freq = 20000;      //probar la freq del buzzer y cualquier cosa cambiar

#define buzzer 13
 
void setup() {
  pinMode(13, OUTPUT);             //Chequear si el 8 está disponible
  
  //-------------------------DISPLAY-----------------------
  // Indicar a la libreria que tenemos conectada una pantalla de 16x2
  //lcd.begin(16, 2);          //PUEDE SER QUE SEA NECESARIO AÑADIR ESTA LINEA Y LA N°6, SACANDO LA 7

  //lcd.init();
  lcd.backlight();    //¿QUEREMOS BACKLIGHT?
  lcd.clear();

  // Mover el cursor a la primera posición de la pantalla (0, 0)
  lcd.home ();
  // Imprimir "Hola Mundo" en la primera linea
  lcd.print("INICIANDO...");
  //-- Mover el cursor a la segunda linea (1) primera columna
  //lcd.setCursor ( 0, 1 );
  // Mover el cursor a la primera posición de la pantalla (0, 0)
  //lcd.clear();

  //-------------------------BÁSCULA-----------------------
  // Iniciar sensor
  Bascula.begin(pinData, pinClk);
  Bascula2.begin(pinData2, pinCLk2);
  // Aplicar la calibración
  Bascula.set_scale(CALIBRACION1);
  Bascula2.set_scale(CALIBRACION2);
  // Iniciar la tara
  // No tiene que haber nada sobre el peso
  Bascula.tare();
  Bascula2.tare()
}
 
void loop() {
  lcd.clear(); //limpio la pantalla (creo XD)
#ifdef DEBUG_HX711  //probablemente borrar

  float peso1 = Bascula.get_units();
  float peso2 = Bascula2.get_units();
  float peso = (peso1+peso2)/2

if (peso>=80){
    while (peso>=80){
      //imprimo el peso abajo
      lcd.setCursor(1,1);
      lcd.print(peso);
      //imprimo una alerta arriba y la borro después de un delay (titila)
      lcd.setCursor(1,0);
      lcd.print("PESO EXCEDIDO");
      delay (1000);
      tone(buzzer, freq, 1000);
      delay(500);
      lcd.clear();
      delay(500);
      
      //limpio la pantalla (creo XD) y actualizo la variable "peso"
      lcd.clear();
      peso1 = Bascula.get_units(); 
      peso2 = Bascula2.get_units();
      peso = (peso1+peso2)/2

    }
  }
else{
    noTone(buzzer); //se podría borrar 
    //Posiciono en segunda columna, segunda fila (cuento desde 0)
    lcd.setCursor(1,1);
    lcd.print(peso);
    
    delay(500);
  }
  

#endif    //probablemente borrar
}

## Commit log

2021-05-09 feat: agregar contenido de pedido
2021-05-09 feat: completar pantalla de pedido
2021-05-09 feat: Hacer pantalla de devolución
2021-05-26 feat: Corrección de Rumbo MOCKUP
2021-05-31 feature: reconocimiento de sector
2021-06-01 Feature/la/js pedido (#4)
    * feat: hacer listado por base de datos
    * feat: terminar el comportamiento de la lista de herramientas
    * feat: agregar comportamiento de la lista peticion
    * feat: agregar barra de busqueda
    * feat: terminar los filtros
2021-06-01 Feature/jmbc/correccion de rumbo (#5)
    * feat: Corrección de Rumbo MOCKUP
    * feature: reconocimiento de sector
2021-06-02 feat: agregar funcionalidad a la pantalla pedido
2021-06-02 feat: regulacion-de-direccion-y-velocidad
2021-06-16 feat: Frenado-de-emergencia
2021-07-05 feat:hice el get de user/pedido del stock y cambios menores para que funcione en conjunto
2021-07-12 docs: Add Documentacion
    [proyecto.kicad_pcb, proyecto.sch]
2021-07-12 Docs: Add celda de carga
    [Celda.dwg]
2021-07-12 docs: Add ESP32
2021-07-12 docs: Add datasheet celda de carga
2021-07-12 feat: Detect magnet twice
2021-08-04 feat:add css to auth forms and error messages
    [forms.py, views.py]
2021-09-03 fix: funciones de las ruedas
    [asyst_carrito_main.py, libs_asyst.py]
2021-09-19 feat: add user/status filter on registros
2021-09-20 feat: add date and word filters
2021-10-01 feature: generar valores de potencia de pwm
2021-11-17 fix: librerías con funciones reducidas
    [libs_asyst.py]
2021-11-17 fix: código main con funcionalidades reducidas
    [asyst_carrito_main.py]
2021-11-19 feature: conectar el esp32 a wifi
2021-11-19 fix: código main y librería de funcionalidades limitadas
    [asyst_carrito_main.py, libs_asyst.py]
2021-11-29 Fix: Nombre de red a conectar
2021-11-29 Fix: cantidad de sensores IFR apreciados
    Se tuvo que reducir la cantidad de sensores apreciados pues uno se quemó
    [libs_asyst.py]
2021-11-29 Fix: correccion de rumbo
    Correspondiente al cambio de apreciacion de sensores se reduce de 4 a 3.
    [libs_asyst.py]
2021-11-29 Fix: nombre y contraseña de red a conectarse
    Esto es útil para la prueba con conexión a computadora
    [asyst_carrito_main.py]
2021-11-29 Fix: reconocimiento de linea
    se redujo de 4 a 3 sensores
    [asyst_carrito_main.py]
2021-11-29 Fix: frenada por ultrasonido
    debido a problemas inesperados se decidió remover esta función temporalmente
    [asyst_carrito_main.py]
2021-11-29 Fix: cantidad de sensores magneticos apreciados
    debido a la ruptura de un sensor magnético se adapto para que funcione con sólo uno
    [asyst_carrito_main.py]
2021-11-29 Fix: comportamiento de ruedas no rquerido
    el error surgió en base a un error en el procesamiento de la detección de imanes
    [asyst_carrito_main.py]
2021-11-29 Refactor: funciones print innecesarias
2021-11-29 Chore: descripciones de las funciones en LIB
2021-11-30 Docs: carrito completo
    [objetos.dwg]
2021-11-30 Docs: celda de carga
    [Celda.dwg]
2021-11-30 Docs: estructura
    [estructura.dwg, estructura3d.dwg]
2021-11-30 Docs: motor
    [motor.dwg]
2021-11-30 Docs: rueda giratoria
    [rueda giratoria.dwg, rueda giratoria3D.dwg]
2021-11-30 Docs: rueda encoder optico
    también incluye el stl utilizado para la impresión de esta
    [encoder opt.stl, rueda optica rpm.dwg]
2021-11-30 Docs: ruedas
    [rueda+adaptador eje motor3d.dwg, ruedaa+daptador eje motor.dwg]
2021-11-30 Docs: soportes ifr y magneticos
    incluye archivos stl usados para impresión 3D
    [Dibujo1.dwg, calibrador.stl, soporte sensores.stl]
2021-11-30 Chore: organizar documentacion de modelos 3D
    [Celda.dwg, Dibujo1.dwg, calibrador.stl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]
2021-11-30 Chore: formato de nombre carpeta
    [Celda.dwg, Dibujo1.dwg, calibrador.stl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]
2021-11-30 Chore: agregar stl de archivos dwg para previsualizar
    [Celda.stl, estructura3d.stl, motor.stl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]
